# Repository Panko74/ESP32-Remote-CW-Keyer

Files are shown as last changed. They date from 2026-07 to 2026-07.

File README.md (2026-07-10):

# ESP32-C6 Remote Keyer

> Remote CW keyer over Internet using ESP32-C6 and raw TCP transport.





Operate your CW station remotely while preserving your exact keying style, timing and fist.

The system consists of two ESP32-C6 devices:

- **TX Unit** connected to a paddle, bug or straight key
- **RX Unit** connected to the radio key input

The transmitter sends keying events over the Internet using a lightweight TCP protocol. The receiver reproduces them in real time on the radio, preserving the original rhythm and characteristics of the operator.

No Morse decoding. No character transmission. No CW regeneration.

Just your keying — remotely.

---

## 📡 Features

✅ Remote CW over TCP/IP

✅ Straight Key, Iambic A, Iambic B and Bug modes

✅ Preserves original operator timing ("fist")

✅ Adjustable latency buffer (0–1000 ms)

✅ OLED SSD1306 support

✅ Built-in Web UI

✅ WiFi 6 capable ESP32-C6 platform

✅ TX / RX / Standalone operating modes

✅ Configuration stored in NVS

✅ Smartphone hotspot compatible

✅ Local sidetone for perfect operator feedback

✅ TCP keepalive and automatic reconnection

---

## 🏗 Architecture

```mermaid
flowchart LR

    PADDLE[Paddle / Bug / Straight Key]
    TX[ESP32-C6 TX]
    NET[(Internet)]
    RX[ESP32-C6 RX]
    RADIO[Radio Transceiver]

    PADDLE --> TX
    TX -->|TCP Port 7373| NET
    NET -->|TCP Port 7373| RX
    RX --> RADIO
```

### TX Unit

- Reads paddle/key inputs
- Generates local sidetone
- Sends timing information via TCP
- Can operate through smartphone hotspot

### RX Unit

- TCP server on port **7373**
- Generates radio keying output
- Independent HTTP configuration server
- Fixed IP mandatory (at the moment)

---

## 📸 Screenshots

### OLED Display

<table>
  <tr>
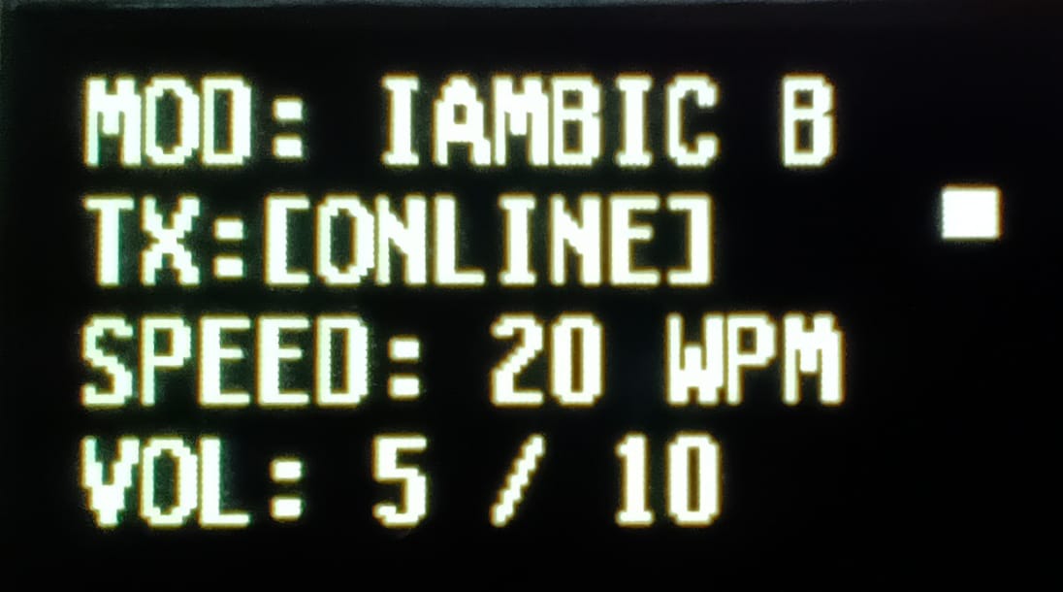
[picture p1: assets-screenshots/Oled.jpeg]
    <td align="center"><br><em>Oled</em></td>
  </tr>
</table>

### Web UI

<table>
  <tr>
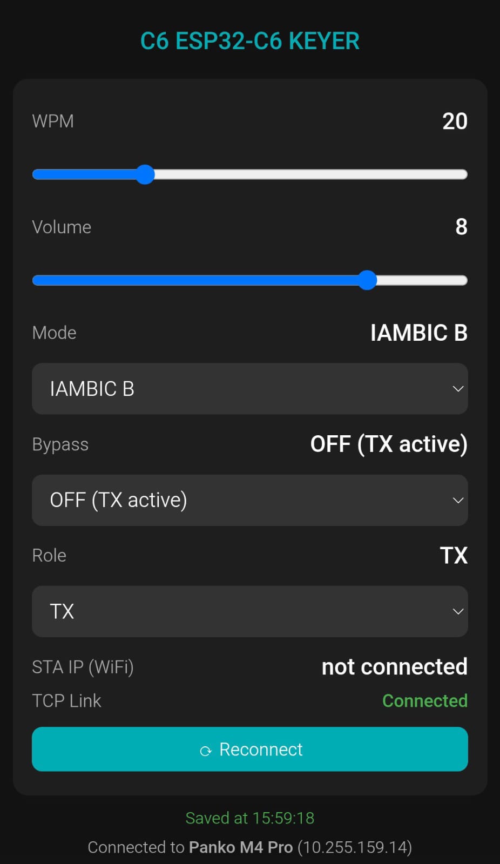
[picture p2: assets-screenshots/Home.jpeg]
    <td align="center"><br><em>Home</em></td>
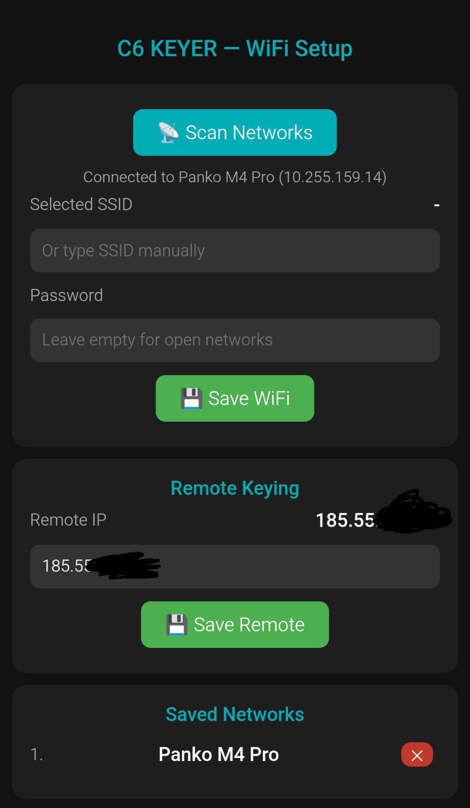
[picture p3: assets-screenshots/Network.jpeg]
    <td align="center"><br><em>Network</em></td>
  </tr>
</table>

---

## ⚡ Quick Start

| Step | Action |
|---|---|
| 1 | Flash firmware on both ESP32-C6 boards |
| 2 | Connect each unit to WiFi |
| 3 | Configure one device as RX |
| 4 | Configure router port forwarding |
| 5 | Configure second device as TX |
| 6 | Start sending CW |

---

# 🔧 Hardware Requirements

- 2 × ESP32-C6 DevKitC-1
- Paddle, bug or straight key
- Radio transceiver with key input
- SSD1306 OLED display (optional)
- USB power supply or battery pack
- Internet connection
- Router with public IP address (RX side)
- Smartphone hotspot or other WiFi with port 7373 open and no captive portal (TX side)

---

# 📍 Pinout

| GPIO | Function | Notes |
|---|---|---|
| GPIO 2 | Paddle DOT | Internal pull-up |
| GPIO 3 | Paddle DASH | Internal pull-up |
| GPIO 4 | WPM UP | Internal pull-up |
| GPIO 5 | WPM DOWN | Internal pull-up |
| GPIO 6 | MODE | Internal pull-up |
| GPIO 7 | RADIO OUTPUT | Via optocoupler/transistor, to radio Key input |
| GPIO 10 | BYPASS | Internal pull-up |
| GPIO 15 | BUZZER | PWM output |
| GPIO 18 | I²C SDA | OLED display |
| GPIO 19 | I²C SCL | OLED display |

The OLED display is optional. The device operates normally without it.

---

# 🌐 Initial Configuration

## 1. Flash Firmware

```bash
# RX

pio run -t upload --upload-port COM8 (i.e.)

# TX

pio run -t upload --upload-port COM9 (i.e.)
```

For a brand-new ESP32-C6, hold BOOT while connecting the USB cable if necessary.

---

## 2. Connect to WiFi

At first boot the device creates:

```text
SSID: C6_KEYER
IP:   192.168.4.1
```

Open:

```text
http://192.168.4.1
```

Navigate to:

```text
WiFi Network Settings
```

Then:

1. Scan Networks
2. Select WiFi
3. Enter password
4. Save Configuration

The device reboots and joins your WiFi network.

---

## 3. Configure RX

Set:

```text
Role = RX
```

Assign a DHCP reservation or static lease on the router.

Example:

```text
192.168.1.50
```

---

## 4. Configure Port Forwarding

Forward TCP port:

```text
7373 → RX_IP:7373
```

Example:

```text
7373 → 192.168.1.50:7373
```

---

## 5. Configure TX

Set:

```text
Role = TX
Remote IP = Public IP of RX router
```

Save and reboot.

The TX automatically connects to the RX.

---

# 🎛 Operating Modes

| Mode | Description |
|---|---|
| Straight | Traditional straight key |
| Iambic A | Squeeze keying supported |
| Iambic B | Iambic A with 1-bit memory |
| Bug | Automatic dots, manual dashes |

---

# 🔘 Buttons

| Button | Short Press | Long Press |
|---|---|---|
| MODE | Cycle keyer mode | — |
| BYPASS | Toggle practice mode | Save settings |
| WPM + | Increase speed | — |
| WPM − | Decrease speed | — |

### Volume Adjustment

Press:

```text
MODE + WPM+
MODE + WPM-
```

to change sidetone volume.

---

# 💻 Web Interface

Every device provides a web interface.

| URL | Purpose |
|---|---|
| / | Main controls |
| /wifi | WiFi and network settings |
| /status | JSON diagnostics |

Examples:

```text
http://192.168.1.50
```

or

```text
http://192.168.4.1
```

when connected through AP mode.

---

# ⚙ How It Works

The TX unit captures paddle events and immediately sends key-down/key-up timing information to the RX unit over a raw TCP connection.

The receiver reproduces those events directly on the radio key input.

Unlike CW-over-text solutions, this system:

- Does not decode Morse characters
- Does not regenerate Morse timing
- Does not alter spacing
- Does not modify weighting

Therefore the transmitted CW retains the exact style ("fist") of the operator.

---

# 🔍 Diagnostics

Serial Monitor:

```bash
pio device monitor -b 115200
```

Common messages:

```text
TCP connected
TCP reconnecting
WiFi STA disconnected
TCP server listening on port 7373
Client connected
```

---

# 🛠 Troubleshooting

## TX does not connect

- Verify port forwarding
- Verify public IP address
- Check firewall rules
- Confirm mobile provider allows outgoing TCP connections

---

## Display not working

- Verify I²C wiring
- Verify pull-up resistors
- Check SSD1306 compatibility

---

## CW stops unexpectedly

- Check TCP connectivity
- Verify Internet stability
- Observe connection indicator on OLED

---

## No audio from buzzer

- Volume may be zero
- Check speaker wiring

---

# 📊 Technical Specifications

| Parameter | Value |
|---|---|
| MCU | ESP32-C6 (RISC-V) |
| CPU | 160 MHz |
| WiFi | 2.4 GHz 802.11 b/g/n/ax |
| Display | SSD1306 OLED |
| WPM Range | 5–70 |
| Latency Buffer | 0–1000 ms |
| Web Server | Port 80 |
| CW TCP Port | 7373 |
| Supply Voltage | 5 V USB or 5V via 15 and 16 pin (i.e. BMS + Li-Ion battery)|
| Consumption | ~200 mA |

---

# 🔨 Build From Source

```bash
git clone https://github.com/Panko74/ESP32-Remote-CW-Keyer.git

cd ESP32RemoteKeyer

pio run

pio run -t upload
```

---

# 🗺 Roadmap

- [X] Wiring schematic
- [ ] OTA firmware updates
- [ ] Dynamic DNS support
- [ ] TLS encrypted transport
- [ ] IPv6 support
- [ ] Battery-powered portable enclosure
- [ ] Embedded battery charging system

---

# 🤝 Contributing

Pull requests, bug reports and enhancement suggestions are welcome.

---

# 📜 License

Released under the MIT License.

73 de IW5DUA

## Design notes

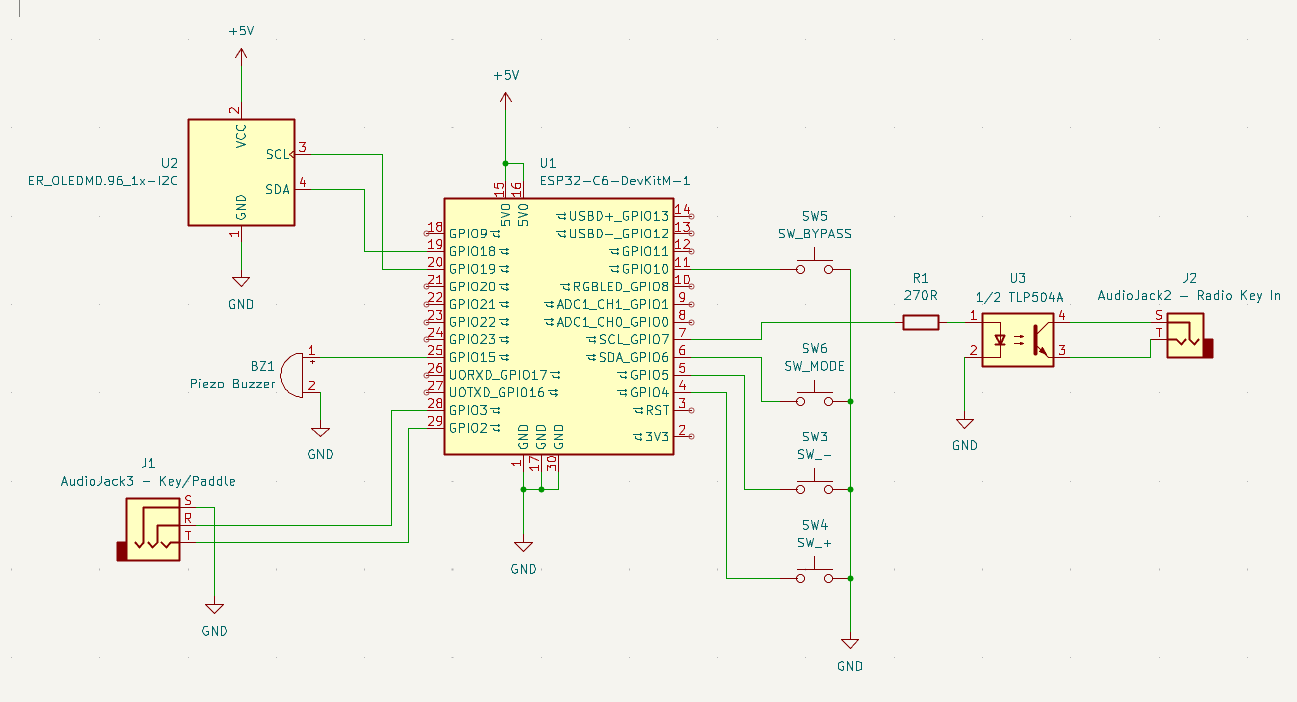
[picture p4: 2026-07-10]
schema/Schema.PNG

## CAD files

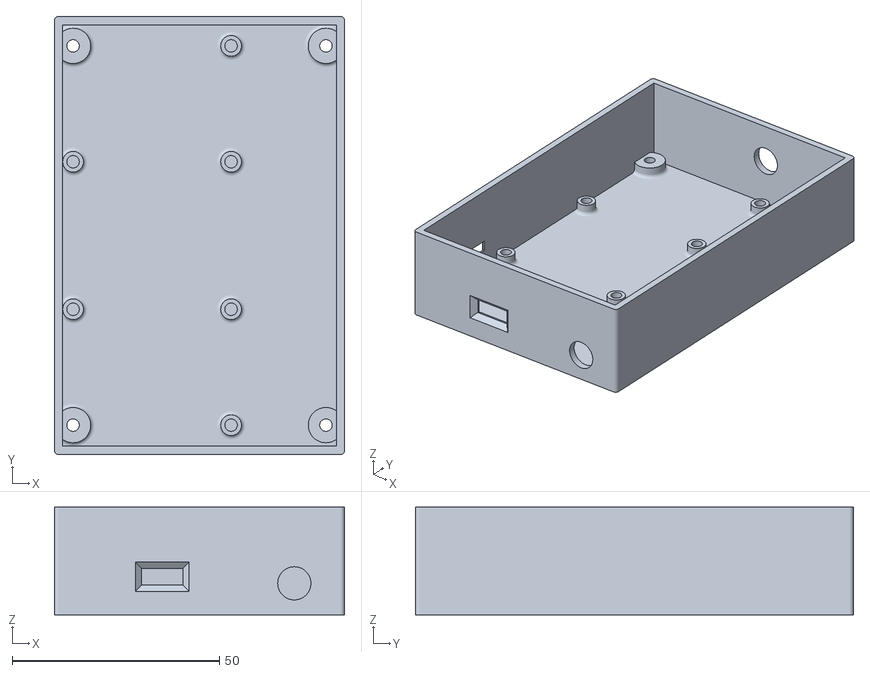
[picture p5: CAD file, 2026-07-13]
Box/Box-Box.stl
70.0 x 105.6 x 26.0

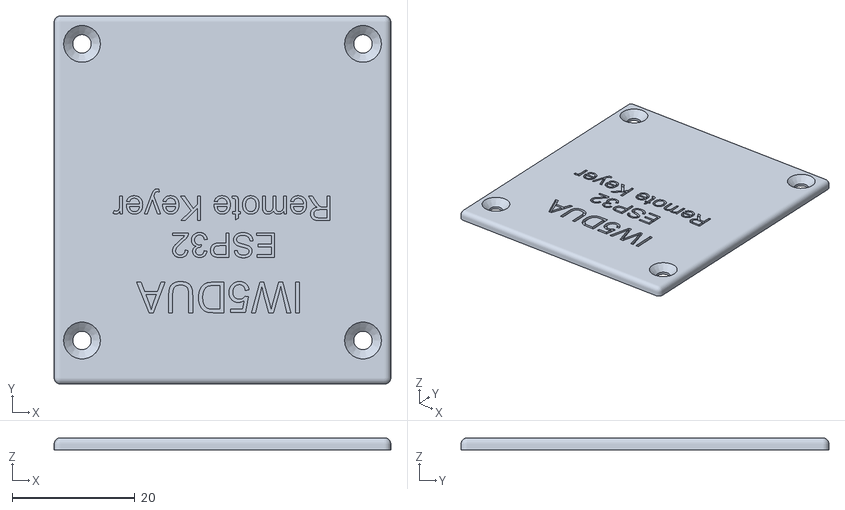
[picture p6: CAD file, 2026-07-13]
Box/Box_RX-Coperchio.stl
54.8 x 59.9 x 2.00

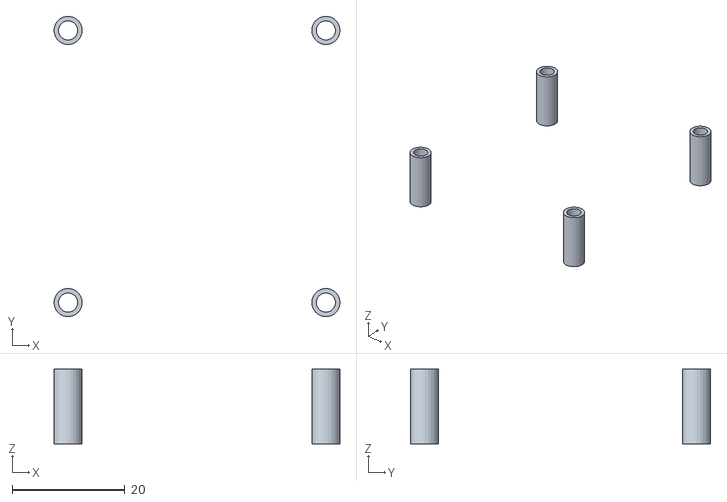
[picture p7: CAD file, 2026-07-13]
Box/Box_RX-Spessori.stl
50.7 x 53.2 x 13.3

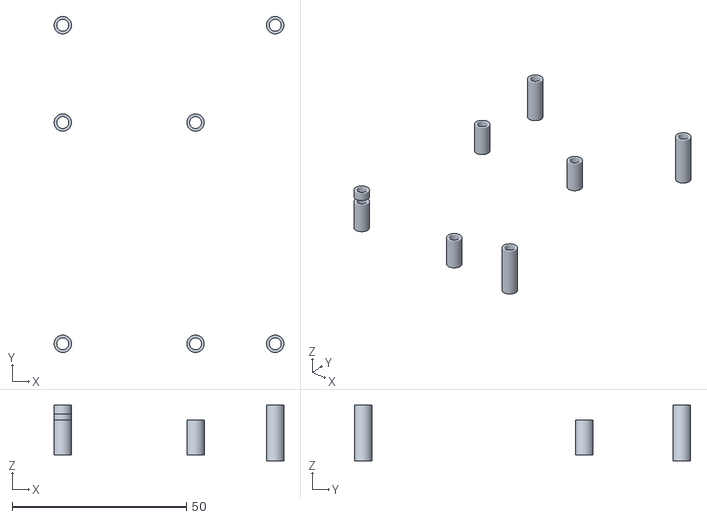
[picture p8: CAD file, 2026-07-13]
Box/Box-Spessori.stl
66.0 x 96.4 x 16.0

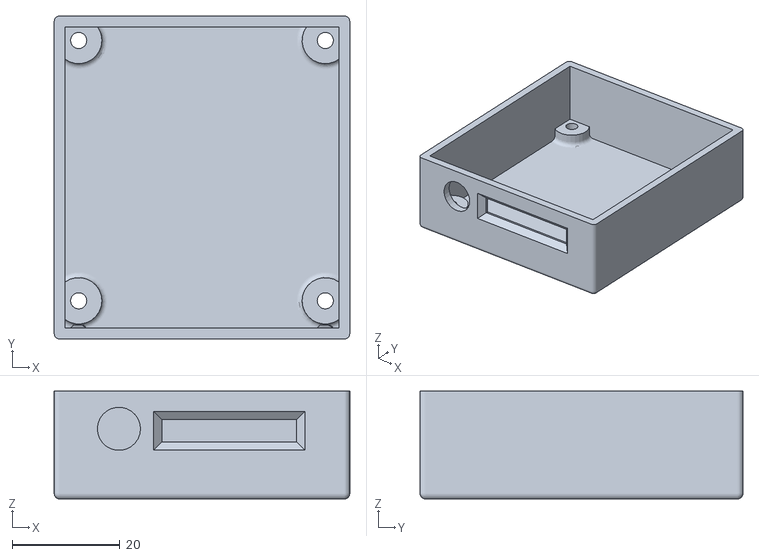
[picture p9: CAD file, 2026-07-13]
Box/Box_RX-Box.stl
54.8 x 59.9 x 20.0

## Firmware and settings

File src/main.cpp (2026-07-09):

#include <stdio.h>
#include <stdlib.h>
#include <string.h>
#include "freertos/FreeRTOS.h"
#include "freertos/task.h"
#include "freertos/semphr.h"
#include "esp_log.h"
#include "nvs_flash.h"
#include "nvs.h"
#include "driver/gpio.h"
#include "driver/ledc.h"
#include "driver/i2c_master.h"
#include "esp_timer.h"
#include "esp_task_wdt.h"
#include "esp_wifi.h"
#include "esp_event.h"
#include "esp_netif.h"
#include "esp_http_server.h"
#include "lwip/sockets.h"
#include "lwip/netdb.h"
#include <arpa/inet.h>
#include "mdns.h"
#include <sys/poll.h>


static const char *TAG = "keyer";

// ============================================================
// PIN CONFIG
// ============================================================
#define PIN_DOT_NUM        2
#define PIN_DASH_NUM       3
#define PIN_OUT_RADIO_NUM  7
#define PIN_BUZZER_NUM     15
#define PIN_WPM_UP_NUM     4
#define PIN_WPM_DOWN_NUM   5
#define PIN_MENU_NUM       6
#define PIN_BYPASS_NUM     10
#define I2C_SDA_PIN_NUM    18
#define I2C_SCL_PIN_NUM    19

#define PIN_DOT       ((gpio_num_t)PIN_DOT_NUM)
#define PIN_DASH      ((gpio_num_t)PIN_DASH_NUM)
#define PIN_OUT_RADIO ((gpio_num_t)PIN_OUT_RADIO_NUM)
#define PIN_BUZZER    ((gpio_num_t)PIN_BUZZER_NUM)
#define PIN_WPM_UP    ((gpio_num_t)PIN_WPM_UP_NUM)
#define PIN_WPM_DOWN  ((gpio_num_t)PIN_WPM_DOWN_NUM)
#define PIN_MENU      ((gpio_num_t)PIN_MENU_NUM)
#define PIN_BYPASS    ((gpio_num_t)PIN_BYPASS_NUM)
#define I2C_SDA_PIN   ((gpio_num_t)I2C_SDA_PIN_NUM)
#define I2C_SCL_PIN   ((gpio_num_t)I2C_SCL_PIN_NUM)

#define PIN_MASK_INPUT ((1ULL<<PIN_DOT_NUM)|(1ULL<<PIN_DASH_NUM)|(1ULL<<PIN_WPM_UP_NUM)|(1ULL<<PIN_WPM_DOWN_NUM)|(1ULL<<PIN_MENU_NUM)|(1ULL<<PIN_BYPASS_NUM))

// ============================================================
// MODES
// ============================================================
#define MODE_STRAIGHT  0
#define MODE_IAMBIC_A  1
#define MODE_IAMBIC_B  2
#define MODE_BUG       3

// ============================================================
// IAMBIC B STATE MACHINE
// ============================================================
#define ELT_IDLE 0
#define ELT_DASH 1
#define ELT_DOT  2
#define ELT_DELAY 3

// ============================================================
// NVS KEYS
// ============================================================
#define NVS_KEY_WPM     "wpm"
#define NVS_KEY_MODE    "mode"
#define NVS_KEY_BYPASS  "bypass"
#define NVS_KEY_VOL     "vol"
#define NVS_KEY_ROLE    "role"
#define NVS_KEY_IP      "rip"
#define NVS_KEY_DISP    "disp"
#define NVS_KEY_JBLAT   "jblat"
#define NVS_KEY_STA_CNT "stacnt"
#define NVS_KEY_STA_SSID "stassid"
#define NVS_KEY_STA_PW  "stapw"

// ============================================================
// SETTINGS (volatile per accesso cross-task)
// ============================================================
typedef struct {
    int32_t wpm;
    int32_t mode;
    int32_t volume;
    int32_t bypass;
    int32_t role;
    char    remote_ip[16];
    int32_t display_enabled;
    int32_t jb_latency;
} keyer_settings_t;

static volatile keyer_settings_t cfg = {
    .wpm = 20,
    .mode = MODE_STRAIGHT,
    .volume = 5,
    .bypass = 0,
    .role = 0,
    .remote_ip = "192.168.1.100",
    .display_enabled = 0,
    .jb_latency = 200,
};

// cfg_mutex will be added in Fase 2 (WiFi)

// ============================================================
// WIFI CREDENTIALS (multi-SSID per STA)
// ============================================================
#define MAX_STA_NETS 4
typedef struct { char ssid[33]; char password[65]; } wifi_cred_t;
static wifi_cred_t sta_creds[MAX_STA_NETS] = {};
static int sta_cred_count = 0;
static volatile bool sta_connected = false;
static volatile bool sta_got_ip = false;
static char sta_ssid_connected[33] = "";
static char sta_ip_str[16] = "";
extern int sta_ap_index;

// ============================================================
// VOLUME TABLE
// ============================================================
static const uint32_t vol_table[] = {0, 2, 5, 12, 28, 60, 120, 250, 450, 650, 833};

// ============================================================
// CW PACKET PROTOCOL (inviato via WebSocket)
// ============================================================
typedef struct __attribute__((packed)) {
    uint8_t type;     // 0x00=OFF, 0x01=ON
    uint32_t ts_ms;   // timestamp mittente (ms)
    uint16_t dur_ms;  // durata impulso in ms (0 per ON, valore effettivo per OFF)
    uint8_t seq;      // sequenziale
} cw_packet_t;

// ============================================================
// KEYER STATE
// ============================================================
static volatile int32_t dot_length_us = 60000;
static volatile bool dot_memory = false;
static volatile bool dash_memory = false;
static volatile bool last_sent_was_dot = false;

// Iambic B state
static volatile int curr_elt = ELT_IDLE;
static volatile int next_elt = ELT_IDLE;
static volatile int last_elt = ELT_IDLE;
static volatile int64_t curr_elt_end_time = 0;
static volatile int64_t idle_since = 0;

// ============================================================
// BUZZER (LEDC PWM)
// ============================================================
static void buzzer_init(void) {
    ledc_timer_config_t lt = {};
    lt.speed_mode = LEDC_LOW_SPEED_MODE;
    lt.duty_resolution = LEDC_TIMER_10_BIT;
    lt.timer_num = LEDC_TIMER_0;
    lt.freq_hz = 600;
    lt.clk_cfg = LEDC_AUTO_CLK;
    ledc_timer_config(&lt);

    ledc_channel_config_t lc = {};
    lc.speed_mode = LEDC_LOW_SPEED_MODE;
    lc.channel = LEDC_CHANNEL_0;
    lc.timer_sel = LEDC_TIMER_0;
    lc.gpio_num = PIN_BUZZER;
    lc.duty = 0;
    lc.hpoint = 0;
    lc.deconfigure = false;
    ledc_channel_config(&lc);
}

static void buzzer_on(void) {
    uint32_t v = cfg.volume;
    if (v <= 0 || v > 10) v = 0;
    uint32_t duty = vol_table[v];
    ledc_set_duty(LEDC_LOW_SPEED_MODE, LEDC_CHANNEL_0, duty);
    ledc_update_duty(LEDC_LOW_SPEED_MODE, LEDC_CHANNEL_0);
}

static void buzzer_off(void) {
    ledc_stop(LEDC_LOW_SPEED_MODE, LEDC_CHANNEL_0, 0);
}

// ============================================================
// RADIO OUTPUT
// ============================================================
static void radio_out(bool state) {
    int32_t b = cfg.bypass;
    if (b) {
        gpio_set_level(PIN_OUT_RADIO, 0);
    } else {
        gpio_set_level(PIN_OUT_RADIO, state ? 1 : 0);
    }
}

static int ws_sock = -1;
static uint8_t pkt_seq = 0;
static int64_t key_start_us = 0;
static volatile bool net_ready = false;
static volatile int tcp_state = 0; // 0=disconnesso 1=connecting(TCP) 2=WS upgrade sent 3=WS connesso
static int64_t tcp_retry_us = 0;   // timestamp prossimo tentativo reconnect
static int64_t tcp_connect_us = 0; // qnd è iniziato il tentativo di connect (per timeout)

// RX: coda per pacchetti ricevuti via WebSocket (net_rx_task la consuma)
static QueueHandle_t rx_pkt_queue = NULL;
static volatile bool ws_client_connected = false;
static volatile bool ws_sync_pending = false;

static void send_key(bool state) {
    static bool last_state = false;

    if (state) buzzer_on(); else buzzer_off();
    radio_out(state);

    // TX via TCP: invia cambio stato se ruolo=TX, bypass=OFF e connesso
    if (cfg.role == 1 && cfg.bypass == 0 && tcp_state == 3 && (state != last_state || ws_sync_pending)) {
        ws_sync_pending = false;
        cw_packet_t pkt;
        pkt.type = state ? 1 : 0;
        int64_t now_us = esp_timer_get_time();
        pkt.ts_ms = (uint32_t)(now_us / 1000);
        pkt.dur_ms = state ? 0 : (uint32_t)((now_us - key_start_us) / 1000);
        pkt.seq = pkt_seq;
        if (state) key_start_us = now_us;
        if (send(ws_sock, &pkt, sizeof(pkt), 0) == sizeof(pkt)) {
            last_state = state;
            pkt_seq++;
        } else if (errno == EAGAIN || errno == EWOULDBLOCK || errno == ENOTCONN || errno == EINPROGRESS || errno == EALREADY) {
        } else {
            ESP_LOGW(TAG, "send_key errno=%d (%s), closing", errno, strerror(errno));
            close(ws_sock); ws_sock = -1; tcp_state = 0; tcp_retry_us = 0;
        }
    }

    // Chiudi socket se non più in ruolo TX
    if (cfg.role != 1 && ws_sock >= 0) {
        close(ws_sock);
        ws_sock = -1;
        tcp_state = 0;
        last_state = false;
        pkt_seq = 0;
    }
}

// ============================================================
// NVS
// ============================================================
static void settings_load(void) {
    nvs_handle_t h;
    if (nvs_open("keyer", NVS_READONLY, &h) != ESP_OK) {
        ESP_LOGW(TAG, "NVS open failed, using defaults");
        return;
    }

    int32_t v_wpm = cfg.wpm, v_mode = cfg.mode, v_byp = cfg.bypass;
    int32_t v_vol = cfg.volume, v_role = cfg.role;
    int32_t v_disp = cfg.display_enabled, v_jbl = cfg.jb_latency;
    char v_ip[16]; strcpy(v_ip, (const char*)cfg.remote_ip);

    nvs_get_i32(h, NVS_KEY_WPM, &v_wpm);
    nvs_get_i32(h, NVS_KEY_MODE, &v_mode);
    nvs_get_i32(h, NVS_KEY_BYPASS, &v_byp);
    nvs_get_i32(h, NVS_KEY_VOL, &v_vol);
    nvs_get_i32(h, NVS_KEY_ROLE, &v_role);
    nvs_get_i32(h, NVS_KEY_DISP, &v_disp);
    nvs_get_i32(h, NVS_KEY_JBLAT, &v_jbl);

    size_t len = sizeof(v_ip);
    nvs_get_str(h, NVS_KEY_IP, v_ip, &len);

    // Carica credenziali WiFi STA
    int32_t sta_cnt = 0;
    nvs_get_i32(h, NVS_KEY_STA_CNT, &sta_cnt);
    if (sta_cnt > MAX_STA_NETS) sta_cnt = MAX_STA_NETS;
    sta_cred_count = sta_cnt;
    for (int i = 0; i < sta_cnt; i++) {
        char key[24];
        size_t sz;
        snprintf(key, sizeof(key), "%s%d", NVS_KEY_STA_SSID, i);
        sz = sizeof(sta_creds[i].ssid);
        nvs_get_str(h, key, sta_creds[i].ssid, &sz);
        snprintf(key, sizeof(key), "%s%d", NVS_KEY_STA_PW, i);
        sz = sizeof(sta_creds[i].password);
        nvs_get_str(h, key, sta_creds[i].password, &sz);
    }

    nvs_close(h);

    if (v_wpm < 5 || v_wpm > 70) v_wpm = 20;
    if (v_mode < 0 || v_mode > 3) v_mode = MODE_STRAIGHT;
    if (v_vol < 0 || v_vol > 10) v_vol = 5;
    if (v_byp < 0) v_byp = 0;
    if (v_role < 0 || v_role > 2) v_role = 0;
    if (v_disp < 0) v_disp = 0;
    if (v_jbl < 50 || v_jbl > 1000) v_jbl = 200;

    cfg.wpm = v_wpm; cfg.mode = v_mode; cfg.bypass = v_byp;
    cfg.volume = v_vol; cfg.role = v_role;
    cfg.display_enabled = v_disp; cfg.jb_latency = v_jbl;
    strcpy((char*)cfg.remote_ip, v_ip);

    dot_length_us = (1200000 / cfg.wpm);
    ESP_LOGI(TAG, "Loaded: WPM=%ld MODE=%ld VOL=%ld BYP=%ld ROLE=%ld DISP=%ld JBLAT=%ld",
             (long)cfg.wpm, (long)cfg.mode, (long)cfg.volume, (long)cfg.bypass, (long)cfg.role,
             (long)cfg.display_enabled);
}

static void settings_save(void) {
    nvs_handle_t h;
    if (nvs_open("keyer", NVS_READWRITE, &h) != ESP_OK) return;

    int32_t v_wpm = cfg.wpm, v_mode = cfg.mode, v_byp = cfg.bypass;
    int32_t v_vol = cfg.volume, v_role = cfg.role;

    nvs_set_i32(h, NVS_KEY_WPM, v_wpm);
    nvs_set_i32(h, NVS_KEY_MODE, v_mode);
    nvs_set_i32(h, NVS_KEY_BYPASS, v_byp);
    nvs_set_i32(h, NVS_KEY_VOL, v_vol);
    nvs_set_i32(h, NVS_KEY_ROLE, v_role);
    nvs_set_i32(h, NVS_KEY_DISP, cfg.display_enabled);
    nvs_set_i32(h, NVS_KEY_JBLAT, cfg.jb_latency);
    nvs_set_str(h, NVS_KEY_IP, (const char*)cfg.remote_ip);

    // Salva credenziali WiFi STA
    nvs_set_i32(h, NVS_KEY_STA_CNT, sta_cred_count);
    for (int i = 0; i < sta_cred_count; i++) {
        char key[24];
        snprintf(key, sizeof(key), "%s%d", NVS_KEY_STA_SSID, i);
        nvs_set_str(h, key, sta_creds[i].ssid);
        snprintf(key, sizeof(key), "%s%d", NVS_KEY_STA_PW, i);
        nvs_set_str(h, key, sta_creds[i].password);
    }

    nvs_commit(h);
    nvs_close(h);
    ESP_LOGI(TAG, "Settings saved");
}

// ============================================================
// PLAY ELEMENT (Iambic A / Bug dot)
// ============================================================
static void play_element(int multiplier) {
    ESP_LOGD(TAG, "play_elt mult=%d dot_us=%ld", multiplier, (long)dot_length_us);
    send_key(true);
    int64_t start = esp_timer_get_time();
    int64_t duration = dot_length_us * multiplier;

    while ((esp_timer_get_time() - start) < duration) {
        esp_task_wdt_reset();
        if (gpio_get_level(PIN_DOT) == 0) dot_memory = true;
        if (gpio_get_level(PIN_DASH) == 0) dash_memory = true;
        vTaskDelay(1);
    }

    send_key(false);

    start = esp_timer_get_time();
    while ((esp_timer_get_time() - start) < dot_length_us) {
        esp_task_wdt_reset();
        if (gpio_get_level(PIN_DOT) == 0) dot_memory = true;
        if (gpio_get_level(PIN_DASH) == 0) dash_memory = true;
        vTaskDelay(1);
    }

    last_sent_was_dot = (multiplier == 1);

    if (gpio_get_level(PIN_DOT) == 1 && gpio_get_level(PIN_DASH) == 1) {
        dot_memory = false;
        dash_memory = false;
    }
}

// ============================================================
// KEYER TASK
// ============================================================
static void disp_sleep(void);
static void disp_wake(void);
static bool disp_sleeping = false;
static uint32_t last_activity_ms = 0;
#define DISP_TIMEOUT_MS 15000
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
extern "C" void app_main(void) {
    ESP_LOGI(TAG, "ESP32-C6 Remote Keyer v1.0");

    // 1. NVS
    esp_err_t ret = nvs_flash_init();
    if (ret == ESP_ERR_NVS_NO_FREE_PAGES || ret == ESP_ERR_NVS_NEW_VERSION_FOUND) {
        ESP_LOGW(TAG, "NVS flash needs erase, doing it");
        nvs_flash_erase();
        nvs_flash_init();
    }
    ESP_LOGI(TAG, "NVS initialized");

    // 2. GPIO (appena possibile per debug seriale)
    gpio_init();
    ESP_LOGI(TAG, "GPIO initialized");

    // 3. Buzzer
    buzzer_init();
    buzzer_off();
    ESP_LOGI(TAG, "LEDC initialized (buzzer on pin %d)", PIN_BUZZER_NUM);

    // 4. Carica impostazioni
    settings_load();
    ESP_LOGI(TAG, "Settings loaded from NVS");

    // 5. Self-test (verifica HW)
    startup_test();
    ESP_LOGI(TAG, "Self-test completed");

    // 6. I2C + OLED display (auto-detect)
    i2c_init();
    if (bus_handle && disp_init()) {
        disp_redraw();
        ESP_LOGI(TAG, "SSD1306 display ready");
    } else {
        ESP_LOGW(TAG, "SSD1306 not detected on I2C bus");
    }

    // 7. Keyer task - priorità media
    xTaskCreate(keyer_task, "keyer", 4096, NULL, 5, NULL);
    ESP_LOGI(TAG, "Keyer task created (prio=5)");

    // 8. Menu task
    xTaskCreate(menu_task, "menu", 4096, NULL, 2, NULL);
    ESP_LOGI(TAG, "Menu task created (prio=2)");

    // 9. WiFi AP+STA + Web Server (solo DNS/beacon su TX)
    wifi_apsta_init();
    web_server_init();
    if (cfg.role == 1) {
        xTaskCreate(dns_server_task, "dns", 2048, NULL, 3, NULL);
        xTaskCreate(beacon_task, "beacon", 2048, NULL, 1, NULL);
    }
    mdns_init();
    mdns_hostname_set("ESP32Keyer");
    mdns_instance_name_set("C6 Keyer");
    mdns_service_add(NULL, "_http", "_tcp", 80, NULL, 0);
    ESP_LOGI(TAG, "WiFi AP+STA + Web Server + DNS + mDNS ready");

    // 10. TCP (TX connect o RX listen in base al ruolo)
    net_init();

    ESP_LOGI(TAG, "Ready. MODE=%s WPM=%ld VOL=%ld BYP=%ld",
             cfg.mode == 0 ? "STRAIGHT" : cfg.mode == 1 ? "IAMBIC A" :
             cfg.mode == 2 ? "IAMBIC B" : "BUG",
             (long)cfg.wpm, (long)cfg.volume, (long)cfg.bypass);
    ESP_LOGI(TAG, "Config: +/WPM=up, MODE=cycle, BYPASS short=toggle long=save");
}

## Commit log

2026-07-09 Initial commit v1.0.0 - ESP32-C6 Remote CW Keyer
    Full-duplex CW keyer pair over TCP raw.
    - TX sends paddle events via TCP port 7373
    - RX receives and plays via buzzer/radio
    - Web UI for configuration
    - OLED display
    - TCP raw transport (no WebSocket)
2026-07-09 Fix: RX tcp_rx_task disconnection on 1s idle timeout
    - RX no longer closes TCP connection after 1s of idle (recv timeout)
    - TCP connection stays alive, waiting for first CW packet
    - Added ws_sync_pending flag for reconnection state sync
    - Increased stuck key recovery to 10s (was 740ms)
    - Changed hostname from espressif to ESP32Keyer
    - Added static IP configuration support
    - Cleaned up debug counters and EVT_LOG
    [main.cpp]
2026-07-10 Add schematic (PNG + KiCad) to repo
    [ESP32Keyer.kicad_sch]
2026-07-10 Revise README for ESP32-C6 Remote Keyer
    Updated README.md to enhance clarity and add features.
2026-07-13 Add Box (STL files for 3D print)
    [Box-Box.stl, Box-Spessori.stl, Box_RX-Box.stl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]

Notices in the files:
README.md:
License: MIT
